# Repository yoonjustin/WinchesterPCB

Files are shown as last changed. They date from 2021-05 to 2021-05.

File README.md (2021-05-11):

# WinchesterPCB
Open source JAMMA supergun project. KiCAD PCB design files, included are the symbols, footprints and BOM. 
The board is a two sided pcb with 1oz copper. Roughly 135mm x 86mm

# Design Breakdown

### Power
Power is supplied using a 20pin atx power connector. That way it can provide +5, -5 and +12v without having to deal with conversion on the pcb itself. In addition, it makes it easy to include a power switch and power led on the pcb. There is also logic in the atx power supply to cut power in the event of a short circuit. Which is a nice safety feature. 
  
The +5v power to the jamma connector needs to be pretty wide and beefy. If we assume 5A through a 1oz copper board thats about 5 inches, a 20 degree raise in temp puts us around 2.59mm trace width. I feel ok with the 2.5mm trace width on the board. Both the +5v and +12v are passing through an INA260 power monitoring IC. The INA260 can handle up to 36v and 15A, so its well within the use of this project. 

The teensy 4.1 uses 100mA, the oled screen 20mA, THS7376 30mA, FE1.1s 142mA, BA7230LS 50mA, and the MIC2026 is less than 1mA. So the total power consumption of the +5v coponents on the board is about 350mA. Using the .6mm trace with feels about right. 

I also made sure not to connect the +5v directly to the pins on the usb ports. The MIC2026-2YM will provide the usb ports with power according to the usb specifications. If anything goes out of spec, the MIC2026 will tell the FE1.1s usb hub to turn off the ports. This should help protect the board and the connected device, incase something goes wrong. 

### Component Video
Jamma arcade games were designed with outputting the video signal to an RGBS compatible display. And when it comes to home compatible tvs, component video is the closest to that signal. Composite video is a more common analog video input, but arcade games wont benefit from any kind of dithering effects.

The RGB signals are passed through individual potentimeters and sent to the BA7230LS to be converted to component signals. Those are then sent to a THS7376 video amplifier and connected to the sync signal which is cleaned up with an LM1881.

The THS7376 video amplifier is a drop in replacement for the THS7374. Either chip is supported in this design. Its worth noting that the 7374 uses much less power than the 7376, but Im not sure how the video quality is between the two. Im not sure if its my crt tv or my eyes, but I dont seem much different enabling and disabling the lowpass filter on the 7376.

### Teensy 4.1
The teensy 3.6 should also work for this design, but considering the 4.1 model is cheaper and faster, I dont see the point in using 3.6 unless you have one on hand. Due to the fact that the teensy 4.1 is not 5v tolerant, I have the pins connected to biased BJT transistors to connect the jamma pins to ground to signal a button press. The transistors have 1k resistors built in connecting the teensy io pin to the base and between the base and the emitter. One small design flaw is that the Player 1 Up signal is using pin 13 on the teensy, which is connected to an led. So every time player presses the up button the led lights up. I was hoping there would be a way to disable the led, but it is hard wired to the pin.

Be careful not to have the atx power and have the teensy plugged in with the onboard micro usb port at the same time. If you do want to have both plugged in and powered at the same time use this guide to do it safely https://www.pjrc.com/teensy/external_power.html. 

### PCB
There are in pad vias in this design. If assembling by hand its not a problem, but some machines do have problems with placing the correct amount of solder the pads with vias.

Both the front and back planes of the pcb are filled with ground. I also added vias along the outside for ground stitching. I dont think its that applicable for this project, but it doesnt hurt anything either. 

All of the connectors, power switch, power led, oled display and potentiometers are using through hole designs incase someone wants to put the board inside of a case. Wires could be ran to connectors on the side of a case. 

The expansion pins are using a footprint of a flat flex connector(SLW8R-5C7LF). A pcb could be mounted on top of the right side, there is another mounting hole near the LM1881 IC. 

### Future Design Considerations
The BA7230LS and FE1.1s are easy to use but not so easy to order and aquire. I have actually gotten some bad BA7230LS's from ebay and it would be nice to use a usb hub with better documentation for robust designs. I wish it had separate OVJ and enable lines for each port. This design from GGLABs converts rgb signals using OPAMPs and it might replace using the BA7230LS https://gglabs.us/sites/gglabs.us/files/a520hd_sch-A00.pdf. As for the usb hub, TI makes a wide variety of hubs but none are using the nice SSOP package.

There is an issue with PS3 controllers locking up the usbhub when connecting, that happens intermittantly. Its puzzling since ps4 and xbox one controllers do not exhibit this behavior. Retrocution sells a usb hub that also uses the FE1.1s and warns not to use pinheaders when connecting usb ports. I wonder if its a connection issue somehow. I also have an issue with using a Hori RAP N model fight stick. It connects for about a second and then disconnects. Either way, using a more modern usb hub from TI would be on the table for a board redesign. 

### Disclaimer
I did include the MIT license to this project, but to I would like to also state:

* I offer NO WARRANTY of any kind and assume NO RESPONSIBILITY for any potential damage caused by this device.
* You are free to build, use, sell, distribute as you like. Please credit and link this project if you are promoting this design

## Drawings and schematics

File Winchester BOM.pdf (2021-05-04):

Designator | Package | Quantity Designation | Description

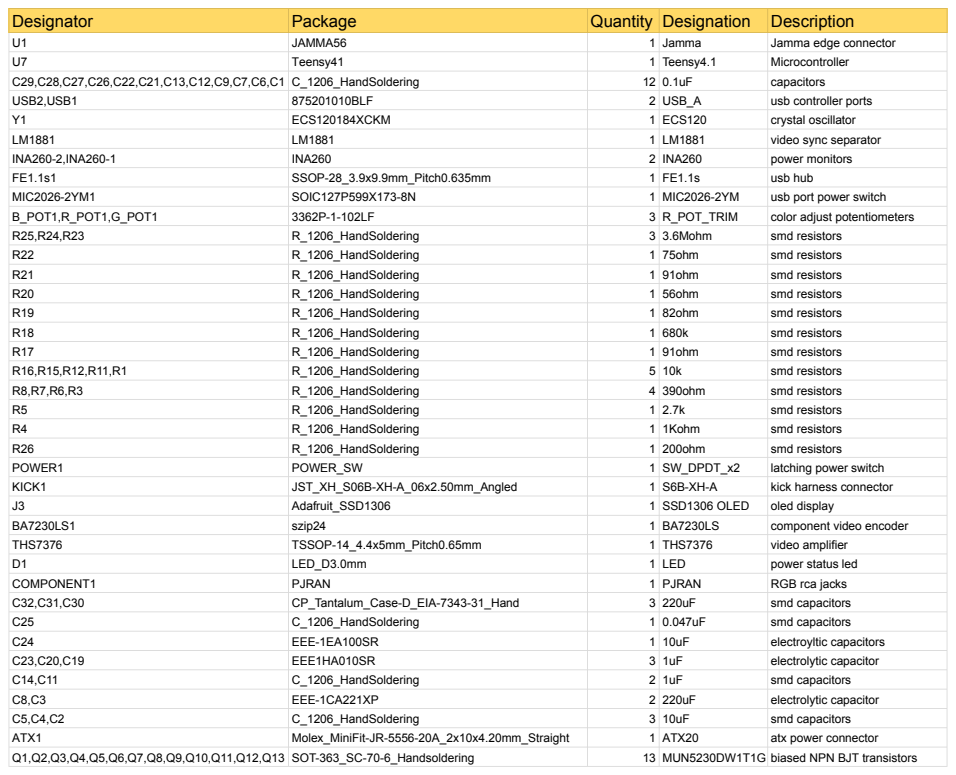
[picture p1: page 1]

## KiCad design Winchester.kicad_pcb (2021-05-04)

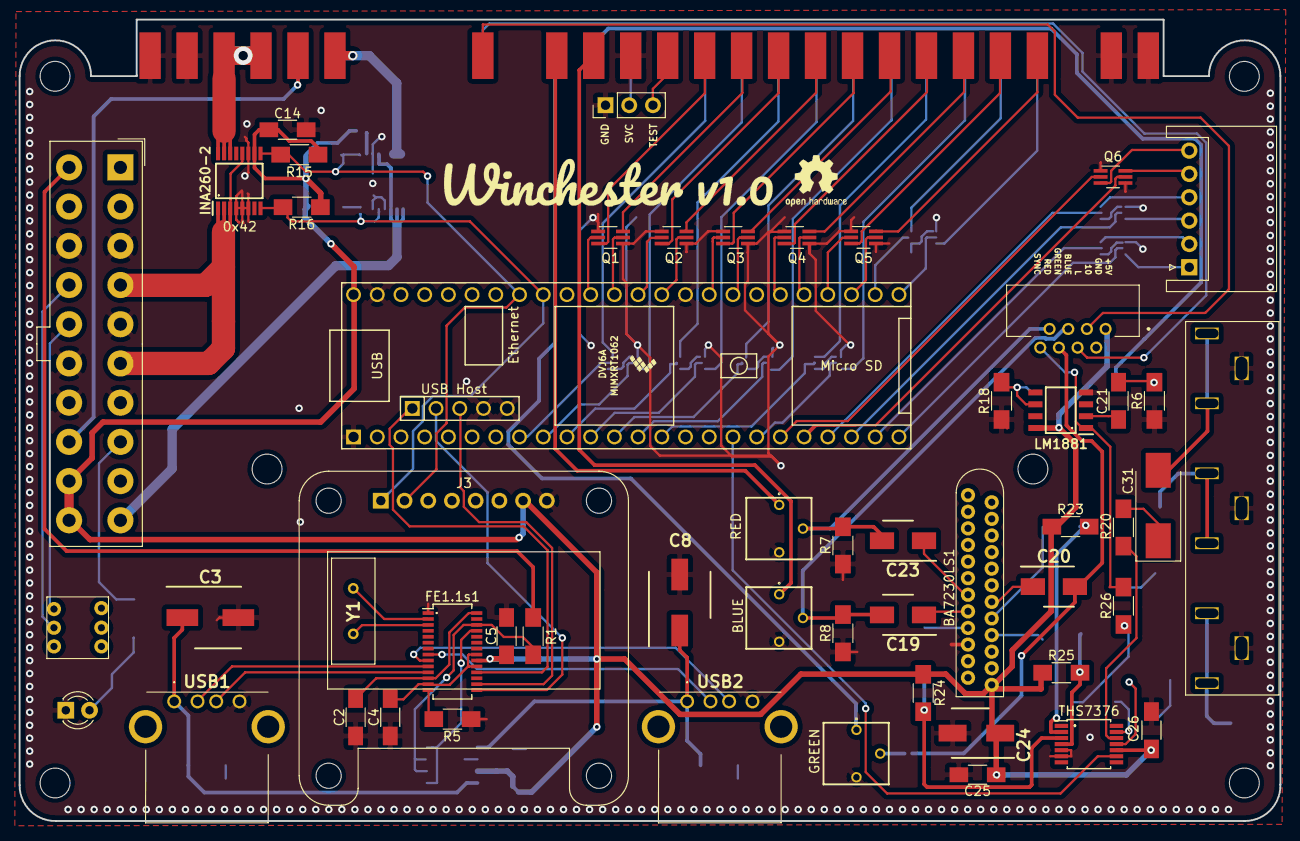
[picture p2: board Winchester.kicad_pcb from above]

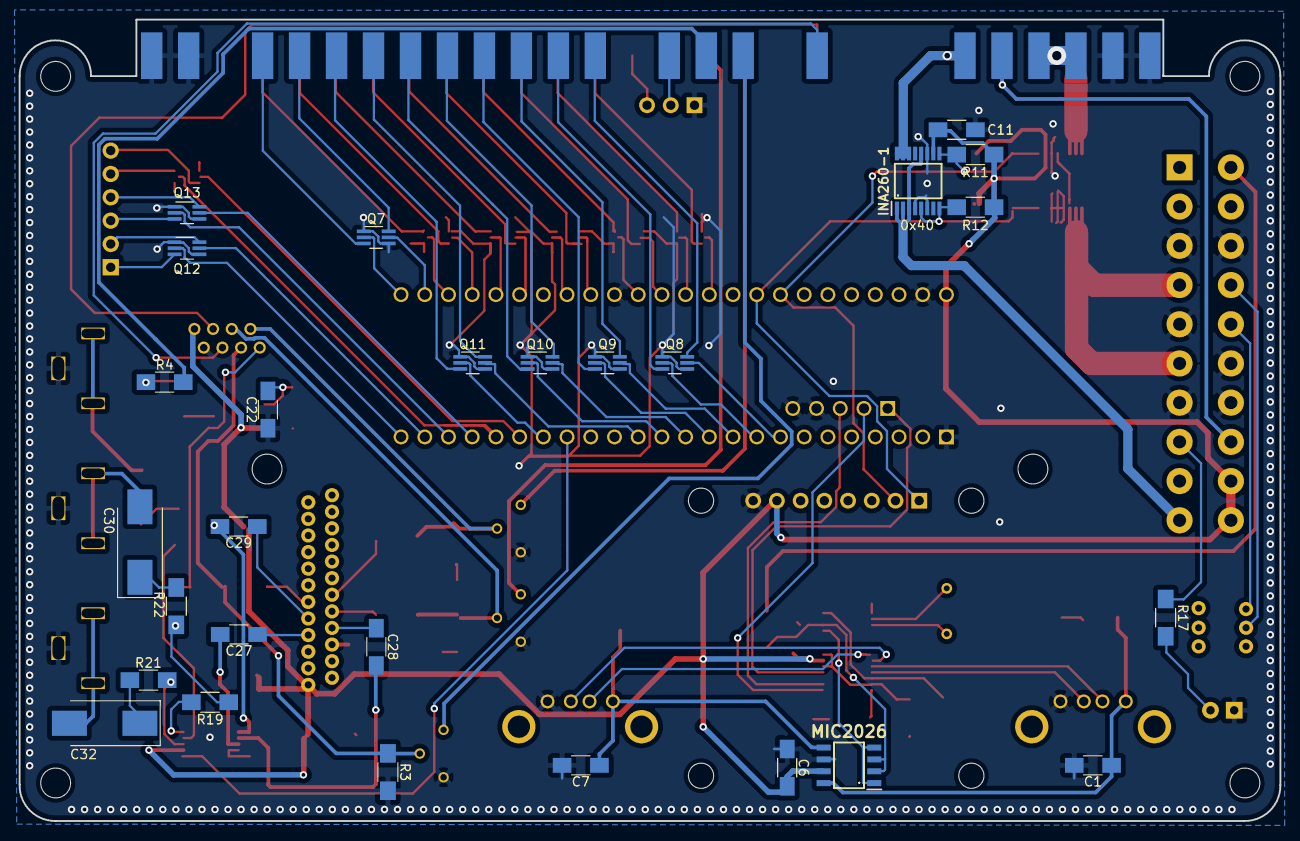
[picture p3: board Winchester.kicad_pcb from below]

Board: 2 copper layers, 135.1 x 85.8 mm, 89 parts (27 on the bottom side), 117 nets.

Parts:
ATX1: ATX20; Molex_MiniFit-JR-5556-20A_2x10x4.20mm_Straight
BA7230LS1: BA7230LS; szip24
B_POT1: R_POT_TRIM; 3362P_1
C1, C6, C7, C21, C22, C26, C27, C28, C29: 0.1uF; C_1206_HandSoldering
C2, C4, C5: 10uF; C_1206_HandSoldering
C3, C8: 220uF; EEE-1CA221XP
C11, C14: 1uF; C_1206_HandSoldering
C19, C20, C23: 1uF; EEE1HA010SR
C24: 10uF; EEE-1EA100SR
C25: 0.047uF; C_1206_HandSoldering
C30, C31, C32: 220uF; CP_Tantalum_Case-D_EIA-7343-31_Hand
COMPONENT1: PJRAN
D1: LED; LED_D3.0mm
FE1.1s1: FE1.1s; SSOP-28_3.9x9.9mm_Pitch0.635mm
G_POT1: R_POT_TRIM; 3362P_1
H1, H2, H3, H4, H5, H6: MountingHole; MountingHole_3.2mm_M3
INA260-1, INA260-2: INA260
J1: Conn_01x03_Female; Pin_Header_Straight_1x03_Pitch2.54mm
J2: SLW8R-5C7LF; SLW8R5C7LF
J3: SSD1306 OLED; Adafruit_SSD1306
KICK1: JST-XH; JST_XH_S06B-XH-A_06x2.50mm_Angled
L1: Logo; v1
LM1881: LM1881
LOGO1: Logo_Open_Hardware_Small; OSHW-Logo2_7.3x6mm_SilkScreen
MIC2026: MIC2026-2YM; SOIC127P599X173-8N
POWER1: SW_DPDT_x2; POWER_SW
Q1, Q2, Q3, Q4, Q5, Q6, Q7, Q8, Q9, Q10, Q11, Q12, Q13: MUN5230DW1T1G; SOT-363_SC-70-6_Handsoldering
R1, R11, R12, R15, R16: 10k; R_1206_HandSoldering
R3, R6, R7, R8: 390ohm; R_1206_HandSoldering
R4: 1Kohm; R_1206_HandSoldering
R5: 2.7k; R_1206_HandSoldering
R17: 330; R_1206_HandSoldering
R18: 680k; R_1206_HandSoldering
R19: 82ohm; R_1206_HandSoldering
R20: 56ohm; R_1206_HandSoldering
R21: 91ohm; R_1206_HandSoldering
R22: 75ohm; R_1206_HandSoldering
R23, R24, R25: 3.6Mohm; R_1206_HandSoldering
R26: 200ohm; R_1206_HandSoldering
R_POT1: R_POT_TRIM; 3362P_1
THS7376: THS7376; TSSOP-14_4.4x5mm_Pitch0.65mm
U1: Jamma; JAMMA56HALF
U7: Teensy4.1; Teensy41
USB1, USB2: USB_A; 875201010BLF
Y1: ECS120; ECS120184XCKM

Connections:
+3V3: ATX1.11, R1.1
+5V: ATX1.19, ATX1.20, BA7230LS1.24, C5.2, C6.2, C11.1, C14.1, C24.1, C25.1, C26.1, FE1.1s1.20, INA260-1.10, INA260-2.10, J2.1, J3.7, LM1881.8, MIC2026.7, R11.1, R12.1, R15.1, R16.1, R23.1, R24.1, R25.1, THS7376.10, U7.48
-5V: ATX1.18, U1.5, U1.E
/10: J2.3, U1.10
/+5VA: ATX1.4, ATX1.6, INA260-2.1, INA260-2.2, INA260-2.3, INA260-2.12
/+5VB: INA260-2.14, INA260-2.15, INA260-2.16, U1.3, U1.4, U1.C, U1.D
/+12VA: ATX1.10, INA260-1.1, INA260-1.2, INA260-1.3, INA260-1.12
/+12VB: INA260-1.14, INA260-1.15, INA260-1.16, U1.6, U1.F
/B: B_POT1.1, U1.13
/B-Y: C28.2, R24.2, THS7376.3
/BLUE: B_POT1.2, C19.2, J2.5, R8.2
/BYPASS: THS7376.9, U7.17
/CH1: C30.2, COMPONENT1.6, COMPONENT1.7
/CH2: C31.2, COMPONENT1.8, COMPONENT1.9
/CH3: C32.2, COMPONENT1.4, COMPONENT1.5
/COIN_P1: Q1.3, U1.16
/COIN_P2: Q8.6, U1.T
/CSYNC: J2.8, LM1881.1, R26.2
/DM: FE1.1s1.15, U7.56
/DM1: FE1.1s1.10, USB1.2
/DM2: FE1.1s1.8, USB2.2
/DP: FE1.1s1.16, U7.57
/DP1: FE1.1s1.11, USB1.3
/DP2: FE1.1s1.9, USB2.3
/ENP: FE1.1s1.25, MIC2026.1, MIC2026.4
/G: G_POT1.1, U1.N
/GREEN: C20.2, G_POT1.2, J2.6, R3.1
/L: J2.4, U1.L
/OVCJ: FE1.1s1.26, MIC2026.2, MIC2026.3, R1.2
/P1_B1: Q4.3, U1.22
/P1_B1_29: Q4.5, U7.29
/P1_B2: Q4.6, U1.23
/P1_B2_30: Q4.2, U7.30
/P1_B3: Q5.3, U1.24
/P1_B3_27: Q5.5, U7.27
/P1_B4: KICK1.1, Q12.3
/P1_B4_23: Q12.5, U7.23
/P1_B4_28: Q5.2, U7.28
/P1_B4_N: Q5.6, U1.25
/P1_B5: KICK1.3, Q13.3
/P1_B5_21: Q13.5, U7.21
/P1_B6: KICK1.5, Q6.6
/P1_B6_19: Q6.2, U7.19
/P1_COIN_37: Q1.5, U7.37
/P1_DOWN: Q2.6, U1.19
/P1_DOWN_36: Q2.2, U7.36
/P1_LEFT: Q3.3, U1.20
/P1_LEFT_32: Q3.5, U7.32
/P1_RIGHT: Q3.6, U1.21
/P1_RIGHT_33: Q3.2, U7.33
/P1_START: Q1.6, U1.17
/P1_START_38: Q1.2, U7.38
/P1_UP: Q2.3, U1.18
/P1_UP_35: Q2.5, U7.35
/P2_B1: Q11.6, U1.Z
/P2_B1_18: Q11.2, U7.18
/P2_B2: Q11.3, U1._a
/P2_B2_14: Q11.5, U7.14
/P2_B3: Q7.6, U1._b
/P2_B3_25: Q7.2, U7.25
/P2_B4: KICK1.2, Q12.6
/P2_B4_24: Q12.2, U7.24
/P2_B4_26: Q7.5, U7.26
/P2_B4_N: Q7.3, U1._c
/P2_B5: KICK1.4, Q13.6
/P2_B5_22: Q13.2, U7.22
/P2_B6: KICK1.6, Q6.3
/P2_B6_20: Q6.5, U7.20
/P2_COIN_9: Q8.2, U7.9
/P2_DOWN: Q9.3, U1.W
/P2_DOWN_10: Q9.5, U7.10
/P2_LEFT: Q10.6, U1.X
/P2_LEFT_13: Q10.2, U7.13
/P2_RIGHT: Q10.3, U1.Y
/P2_RIGHT_12: Q10.5, U7.12
/P2_START: Q8.3, U1.U
/P2_START_8: Q8.5, U7.8
/P2_UP: Q9.6, U1.V
/P2_UP_11: Q9.2, U7.11
/R: R_POT1.1, U1.12
/R-Y: C27.2, R25.2, THS7376.4
/RED: C23.2, J2.7, R7.2, R_POT1.2
/S: R4.2, U1.P
/SCL: INA260-1.9, INA260-2.9, J3.2, R11.2, R15.2, U7.41
/SDA: INA260-1.5, INA260-1.8, INA260-2.8, J3.1, R12.2, R16.2, U7.40
/SERVICE: J1.2, U1.R
/SYNC: C21.2, R4.1, R6.2
/TEST: J1.3, U1.15
/USBA5V: C1.1, C3.1, MIC2026.8, USB1.1
/USBB5V: C7.1, C8.1, MIC2026.5, USB2.1
/USBVCC: FE1.1s1.18, U7.55
/Y: C29.2, R23.2, THS7376.2
GND: ATX1.3, ATX1.5, ATX1.7, ATX1.13, ATX1.16, ATX1.17, BA7230LS1.19, B_POT1.3, C1.2, C2.1, C3.2, C4.1, C5.1, C6.1, C7.2, C8.2, C11.2, C14.2, C22.1, C24.2, C25.2, C26.2, COMPONENT1.1, COMPONENT1.2, COMPONENT1.3, D1.1, FE1.1s1.1, G_POT1.3, INA260-1.4, INA260-1.6, INA260-1.11, INA260-2.4, INA260-2.5, INA260-2.6, INA260-2.11, J1.1, J2.2, J3.8, LM1881.4, MIC2026.6, Q1.1, Q1.4, Q2.1, Q2.4, Q3.1, Q3.4, Q4.1, Q4.4, Q5.1, Q5.4, Q6.1, Q6.4, Q7.1, Q7.4, Q8.1, Q8.4, Q9.1, Q9.4, Q10.1, Q10.4, Q11.1, Q11.4, Q12.1, Q12.4, Q13.1, Q13.4, R3.2, R5.2, R6.1, R7.1, R8.1, R18.1, R_POT1.3, THS7376.5, THS7376.6, U1.1, U1.2, U1.14, U1.27, U1.28, U1.A, U1.B, U1._e, U1._f, U7.1, U7.34, U7.47, U7.58, U7.59, USB1.4, USB2.4
unnamed: ATX1.8, R17.1
unnamed: ATX1.14, POWER1.3
unnamed: ATX1.15, POWER1.1
unnamed: BA7230LS1.13, C23.1
unnamed: BA7230LS1.14, C20.1
unnamed: BA7230LS1.15, C19.1
unnamed: BA7230LS1.16, C29.1
unnamed: BA7230LS1.17, C28.1
unnamed: BA7230LS1.18, C27.1
unnamed: C2.2, FE1.1s1.12, FE1.1s1.28
unnamed: C4.2, FE1.1s1.13, FE1.1s1.19, FE1.1s1.21
unnamed: C21.1, LM1881.2
unnamed: C22.2, LM1881.6, R18.2
unnamed: C30.1, R22.1
unnamed: C31.1, R20.1
unnamed: C32.1, R21.1
unnamed: D1.2, R17.2
unnamed: FE1.1s1.2, Y1.2
unnamed: FE1.1s1.3, Y1.1
unnamed: FE1.1s1.14, R5.1
unnamed: R19.1, R22.2, R26.1
unnamed: R19.2, THS7376.13
unnamed: R20.2, THS7376.12
unnamed: R21.2, THS7376.11
